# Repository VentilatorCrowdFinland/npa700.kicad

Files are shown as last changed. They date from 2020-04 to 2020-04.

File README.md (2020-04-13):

# NPA-7xx breakout board 

This board supports NPA-7xx series differential pressure sensors. 

## Board pinout 

1) VDD, 3.135 V to 3.465 V for NPA-730 series and 4.75 V to 5.25 V to NPA-700 series
2) PIN1 SCL
3) PIN2 SDA
4) PIN3 GPIO3 - Sensor version detect 1
5) PIN4 GPIO4 - Sensor version detect 2
6) PIN5 GPIO5 - Sensor version detect 3
7) PIN6 - NC, keying for assembly
8) GND

| GPIO3 | GPIO4 | GPIO5 | Sensor |
| ----- | ----- | ----- | --- |
| HI | HI | LO/NC | Reserved |
| LO/NC | HI | LO/NC | NPA-7xx-030D |
| HI | LO/NC | LO/NC | NPA-7xx-015D |
| LO/NC | LO/NC | LO/NC | NPA-7xx-005D |
| HI | HI | LO/NC | NPA-7xx-001D |
| LO/NC | HI | LO/NC | NPA-7xx-10WD |
| HI | LO/NC | LO/NC | NPA-7xx-05WD |
| LO/NC | LO/NC | LO/NC | NPA-7xx-02WD |

## Dimensions of expansion board

* Outline 17.5 x 32.5 mm (17.5 x 25 mm without mounting holes)
* Minimum drill 0.3 mm, annular 0.6 mm, trace 0.25 mm, isolation 0.15 mm.
* Any board thickness and plating.
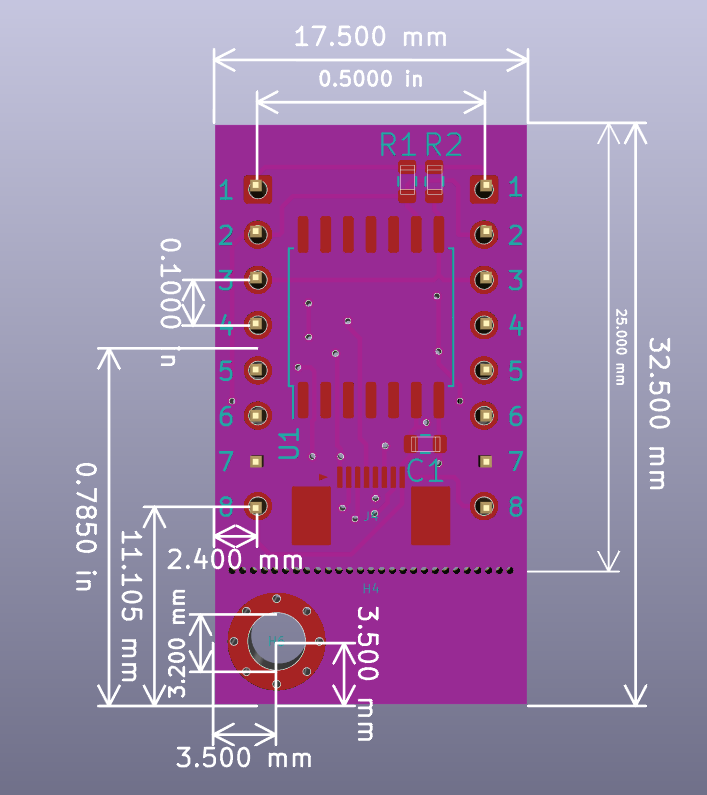
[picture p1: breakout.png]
NPA-7XX breakout


## Exports
In addition to KiCAD source files, Gerbers and PDF export is available under exports of
each project folder.

## Versioning
Versions which begin with same letter (e.g. 'B') are interface-compatible: Their mounting holes
and signals are at the same places. Revisions might have internal changes, such as different routing or
component placement.

Versions which begin with different letter are not backward compatible, i.e. mounting holes or dimensions of board
may have changed. 

## Licenses

This board is based on [Ruuvi Connector board](https://github.com/ruuvi/connector) which is
CC BY-SA 4.0 licensed. 

Footprints are from 
 * [Ruuvi/KiCAD-library](https://www.ohwr.org/project/cernohl/wikis/uploads/8a6b5d01f71c207c49493e4d114d61e6/cern_ohl_p_v2_howto.pdf) 
which aren't licensed in any manner.
 * [ojousima.footprints.kicad](https://github.com/ojousima/ojousima.footprints.kicad/tree/0481a381fbb01a2b40545e94f72d81239064c85a) which is MIT-licensed.

A permission to publish this package under CERN-OHL-P has been requested, but not yet granted. In meanwhile, entire project inherits 
CC BY-SA from Ruuvi Connector design.

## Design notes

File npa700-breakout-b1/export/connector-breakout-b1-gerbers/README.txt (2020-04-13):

Project NPA-7xx breakout B1.

Files:
Bottom copper npa700-breakout-b1-B_Cu.gbl
Top copper npa700-breakout-b1-F_Cu.gtl

Bottom mask npa700-breakout-b1-B_Mask.gbs
Top mask npa700-breakout-b1-B_Mask.gts

Bottom paste npa700-breakout-b1-B_Paste.gbp
Top paste npa700-breakout-b1-B_Mask.gtp

Edges npa700-breakout-b1-Edge_Cuts.gml

Plated through holes npa700-breakout-b1-PTH.drl
Non-Plated through holes npa700-breakout-b1-NPTH.drl

X-Y positions of components npa700-breakout-b1-top.pos

Board:
Layers 2
Thickness 1.5 .. 1.6 mm
Copper thickness 35 um
Min trace 0.25 mm
Min drill 0.3 mm 
Min annular ring 0.6 mm
Min isolation 0.15 mm
Surface finish ENIG

Assembly:
IMPORTANT: Pin headers are on the bottom side of the board and pin 7 must be removed from
the headers.

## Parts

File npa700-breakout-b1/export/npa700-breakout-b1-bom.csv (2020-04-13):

Id | Designator | Package | Quantity | Designation | Supplier and ref
1 | J3,J2 | RUUVI_CONNECTOR_8PIN_HEADER | 2 | Ruuvi Connector Pin Header
2 | H6 | MountingHole_3.2mm_M3_Pad_Via | 1 | MountingHole
3 | H4 | BreakoutHoles | 1 | 27 x 0.4mm NPTH
4 | C1 | CAPC160X80X35L25N | 1 | 100n
5 | R1,R2 | CAPC160X80X35L25N | 2 | 10k
6 | U1 | SOIC-14W_7.5x9mm_P1.27mm | 1 | NPA-700
7 | J4 | RUUVI_CONNECTOR_FFC | 1 | Ruuvi Connector Horizontal
8 | JP1,JP2,JP3 | SolderJumper-3_P2.0mm_Open_TrianglePad1.0x1.5mm_NumberLabels | 3 | SolderJumper_3_Open

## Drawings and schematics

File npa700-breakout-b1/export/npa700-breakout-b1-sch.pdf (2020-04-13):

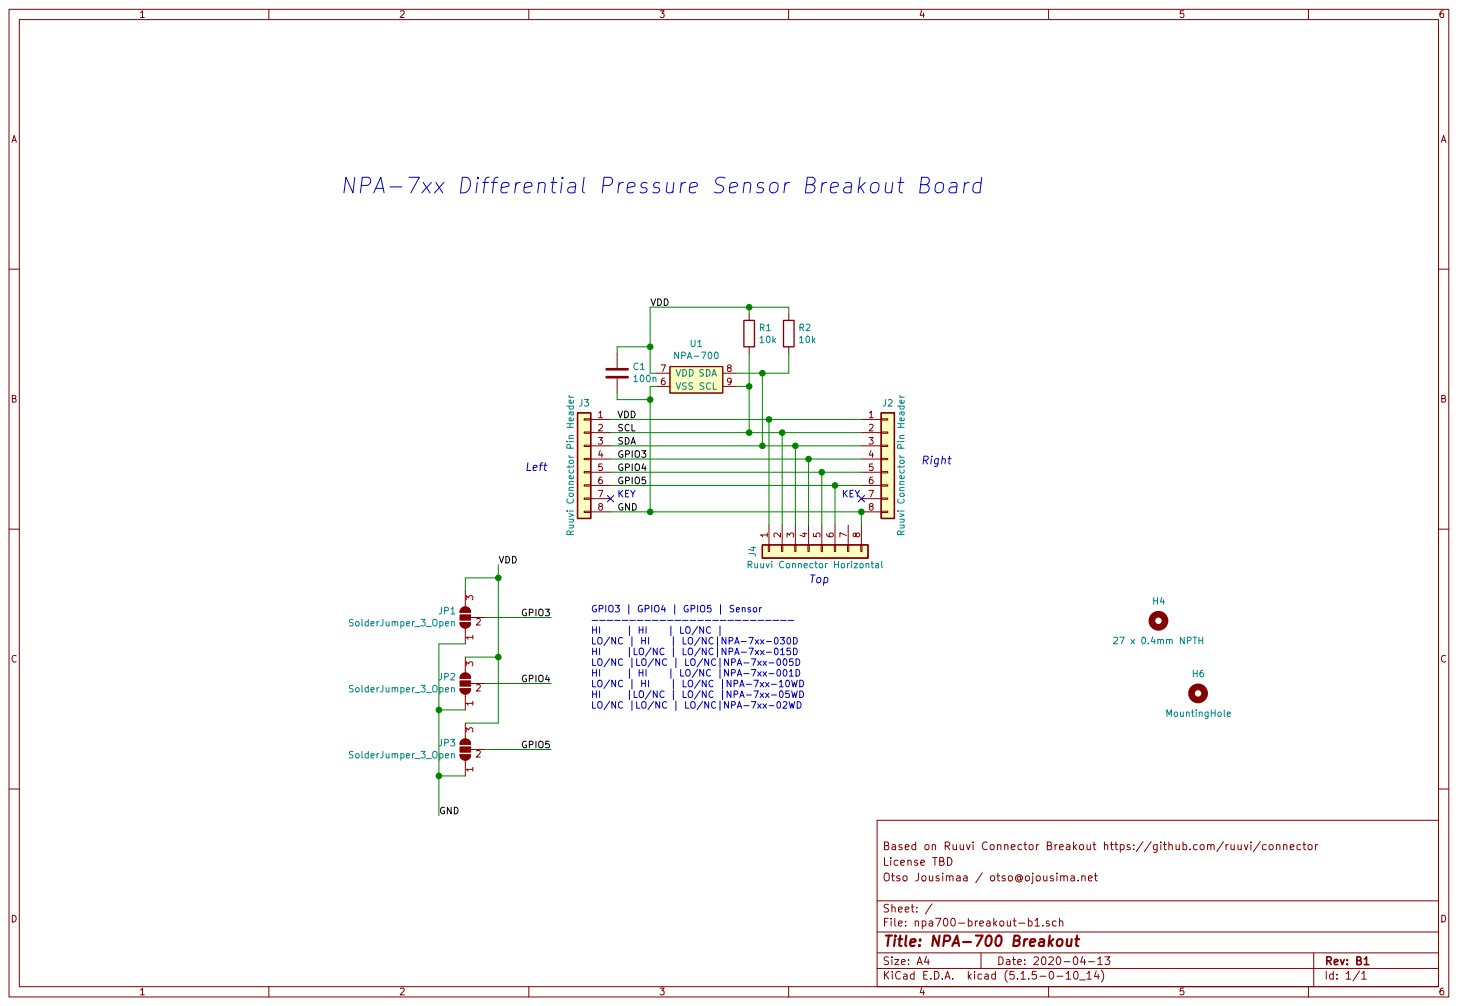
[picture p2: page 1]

VDD GND
J3 Ruuvi Connector Pin Header 1 2

3 SDA | 3 | J2 Ruuvi Connector Pin Header1

7 KEY 8 | | | | | KEY 7

LO/NC | HI | LO/NC|NPA-7xx-030D
HI |LO/NC | LO/NC|NPA-7xx-015D
LO/NC |LO/NC | LO/NC|NPA-7xx-005D
LO/NC | HI | LO/NC |NPA-7xx-10WD
HI |LO/NC | LO/NC |NPA-7xx-05WD
LO/NC |LO/NC | LO/NC|NPA-7xx-02WD

Based on Ruuvi Connector Breakout https://github.com/ruuvi/connector
File: npa700-breakout-b1.sch Sheet: / Otso Jousimaa / otso@ojousima.net License TBD

Id: 1/1 Title: NPA-700 Breakout

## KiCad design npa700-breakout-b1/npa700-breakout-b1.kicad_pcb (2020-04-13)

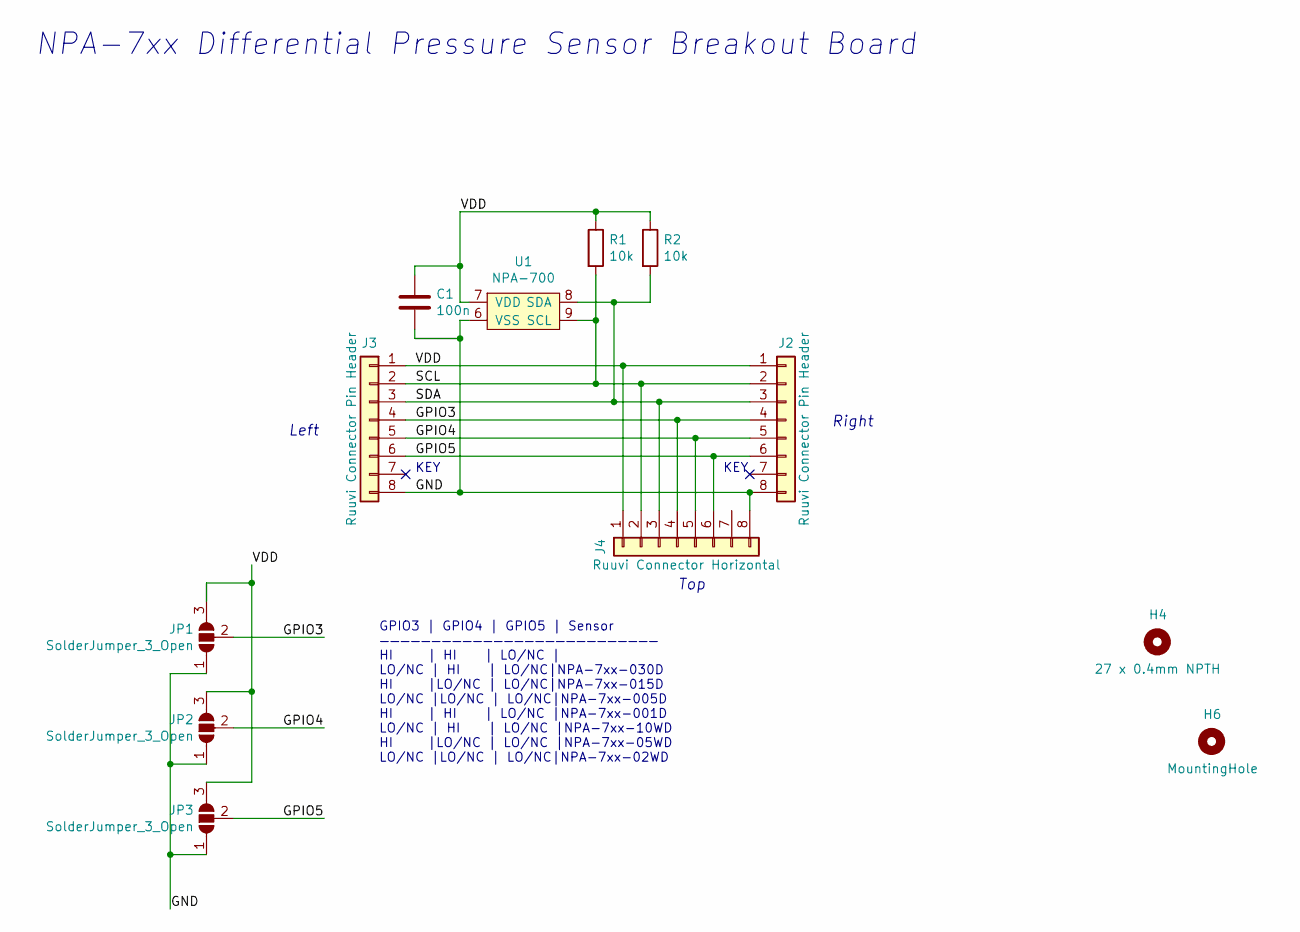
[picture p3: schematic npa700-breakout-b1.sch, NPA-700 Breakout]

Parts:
C1: 100n; CAPC160X80X35L25N
H4: 27 x 0.4mm NPTH; BreakoutHoles
H6: MountingHole; MountingHole_3.2mm_M3_Pad_Via
J2, J3: Ruuvi Connector Pin Header; RUUVI_CONNECTOR_8PIN_HEADER
J4: Ruuvi Connector Horizontal; RUUVI_CONNECTOR_FFC
JP1, JP2, JP3: SolderJumper_3_Open; SolderJumper-3_P2.0mm_Open_TrianglePad1.0x1.5mm_NumberLabels
R1, R2: 10k; CAPC160X80X35L25N
U1: NPA-700; SOIC-14W_7.5x9mm_P1.27mm

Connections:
/GND: C1.1, J2.8, J3.8, J4.8, JP1.1 (A), JP2.1 (A), JP3.1 (A), U1.6 (VSS)
/GPIO3: J2.4, J3.4, J4.4, JP1.2 (C)
/GPIO4: J2.5, J3.5, J4.5, JP2.2 (C)
/GPIO5: J2.6, J3.6, J4.6, JP3.2 (C)
/SCL: J2.2, J3.2, J4.2, R1.2, U1.9 (SCL)
/SDA: J2.3, J3.3, J4.3, R2.2, U1.8 (SDA)
/VDD: C1.2, J2.1, J3.1, J4.1, JP1.3 (B), JP2.3 (B), JP3.3 (B), R1.1, R2.1, U1.7 (VDD)

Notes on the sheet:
NPA-7xx Differential Pressure Sensor Breakout Board
Top
Left
Right
GPIO3 | GPIO4 | GPIO5 | Sensor ——————————————————————————— HI | HI | LO/NC | LO/NC | HI | LO/NC|NPA-7xx-030D HI |LO/NC | LO/NC|NPA-7xx-015D LO/NC |LO/NC | LO/NC|NPA-7xx-005D HI | HI | LO/NC |NPA-7xx-001D LO/NC | HI | LO/NC |NPA-7xx-10WD HI |LO/NC | LO/NC |NPA-7xx-05WD LO/NC |LO/NC | LO/NC|NPA-7xx-0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
KEY

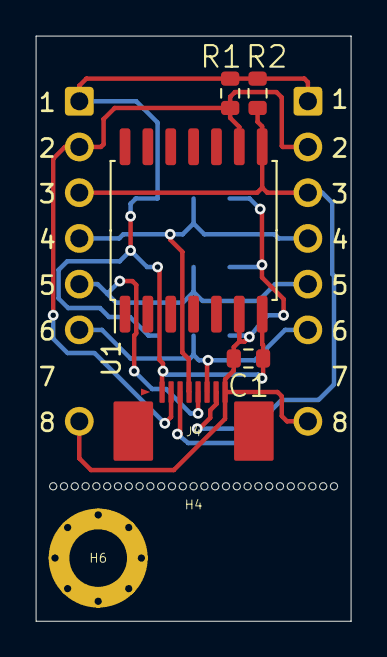
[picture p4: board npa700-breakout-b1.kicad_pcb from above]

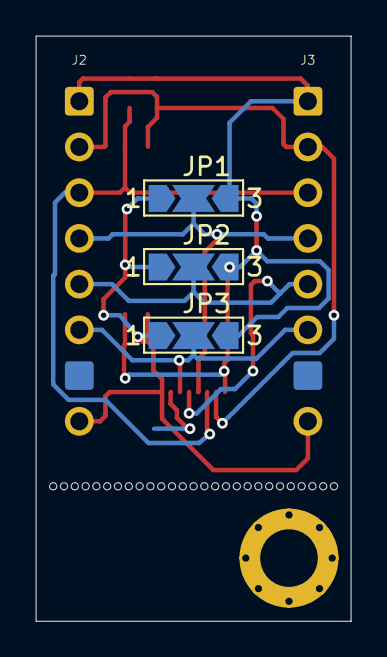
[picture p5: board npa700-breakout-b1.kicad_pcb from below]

Board: 2 copper layers, 17.5 x 32.5 mm, 12 parts (5 on the bottom side), 7 nets.

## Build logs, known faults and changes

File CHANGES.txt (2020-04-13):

# Changes

## B1
 - Fork the project for VCF.
 - Key the pinheader pin 7.
 - Remove 3 mounting holes, one snap-off edge.
 - Move remaining mounting hole in corner.

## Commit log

2020-04-10 First draft
    [connector-breakout-a1.kicad_pcb, connector-breakout-a1.sch]
2020-04-10 Add gerbers
    [connector-breakout-a1-B_Cu.gbl, connector-breakout-a1-B_Mask.gbs, connector-breakout-a1-B_Paste.gbp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]
2020-04-10 Rename board
    [connector-breakout-a1-B_Cu.gbl, connector-breakout-a1-B_Mask.gbs, connector-breakout-a1-B_Paste.gbp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]
2020-04-13 B1 files
    [connector-breakout-a1-B_Cu.gbl, connector-breakout-a1-B_Mask.gbs, connector-breakout-a1-B_Paste.gbp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]

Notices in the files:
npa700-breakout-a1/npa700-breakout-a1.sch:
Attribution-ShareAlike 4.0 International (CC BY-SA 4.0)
